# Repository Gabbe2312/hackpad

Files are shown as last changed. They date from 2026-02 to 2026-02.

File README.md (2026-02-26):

# Hackpad

Hackpad is a hardware-assisted penetration testing input device designed to accelerate reconnaissance workflows.  
It combines a physical keypad interface with USB HID keyboard emulation to launch predefined security tools directly from a target system.

⚠ This tool is intended strictly for authorized security testing and educational purposes.

---

## Photos

Hackpad Top

**More angles:**
Hackpad Side
Hackpad Desk
Hackpad Buttons

## How It Works

1. User enters target IPv4 address.
2. Optional TCP port can be specified.
3. One or more tools are selected.
4. Hackpad opens a terminal (Hyprland Super+Enter).
5. The selected commands are typed automatically via USB HID.

No software is installed on the target system — the device acts as a keyboard.

---

## Physical Key Layout

The keypad is physically labeled for intuitive operation (Mode, Clear, Port, Backspace, Enter, Opt1–Opt3, Hack).  
Internally, the firmware maps these labels to key events as follows:

| Button label | Firmware key | Function |
|---|---:|---|
| Mode | `M` | Switch between IP and Web tool banks |
| Clear | `C` | Clear current input (IP/port) |
| Port | `P` | Toggle between IP and Port edit mode |
| Backspace | `B` | Delete last character |
| Enter | `E` | Validate + save current input |
| Opt1 | `n` | Toggle tool 1 (Nmap / sqlmap) |
| Opt2 | `i` | Toggle tool 2 (Nikto / WhatWeb) |
| Opt3 | `g` | Toggle tool 3 (Gobuster / theHarvester) |
| Hack | `h` | Execute selected tools |

## Features

- IPv4 and TCP port input via physical keypad
- Dual tool banks (IP tools / Web tools)
- Integrated 16x2 I2C LCD interface
- USB HID keyboard emulation (no drivers required)
- Norwegian keyboard layout support
- Input validation (IPv4 + port range checking)
- Modular command execution per selected tool

---

## Supported Tools

### IP Tool Bank
- Nmap
- Nikto
- Gobuster

### Web Tool Bank
- sqlmap
- WhatWeb
- theHarvester

---

## Hardware Overview

- Arduino Pro Micro (ATmega32U4)
- 4x5 matrix keypad
- 16x2 I2C LCD display (0x27)
- USB connection to host machine

---

## Physical Interface

Hackpad Top

The keypad is physically labeled for intuitive operation:

| Button label | Firmware key | Function |
|---|---:|---|
| Mode | M | Switch between IP and Web tool banks |
| Clear | C | Clear current input (IP/port) |
| Port | P | Toggle between IP and Port edit mode |
| Backspace | B | Delete last character |
| Enter | E | Save current input |
| Opt1 | n | Toggle tool 1 (Nmap / sqlmap) |
| Opt2 | i | Toggle tool 2 (Nikto / WhatWeb) |
| Opt3 | g | Toggle tool 3 (Gobuster / theHarvester) |
| Hack | h | Execute selected tools |

## Building / Flashing

### Required Libraries
- Keypad
- LiquidCrystal_I2C
- HID-Project (NicoHood)

Board selection:
- Arduino Leonardo / Pro Micro (ATmega32U4)

Upload via Arduino IDE.

---

# Hardware 

## Microcontroller
- Arduino Pro Micro (ATmega32U4, 5V / 16MHz)

## Display
- 16x2 LCD Display
- I2C Backpack (PCF8574, address 0x27)

## Input System
- 20x Mechanical switches (4x5 matrix)
- 20x 1N4148 diodes
- Handwired matrix

## Enclosure
- 3D printed case (PLA)
- 3D printed keycaps with engraved labels

## Additional
- USB cable (Micro-USB)
- Jumper wires

## 3D Enclosure

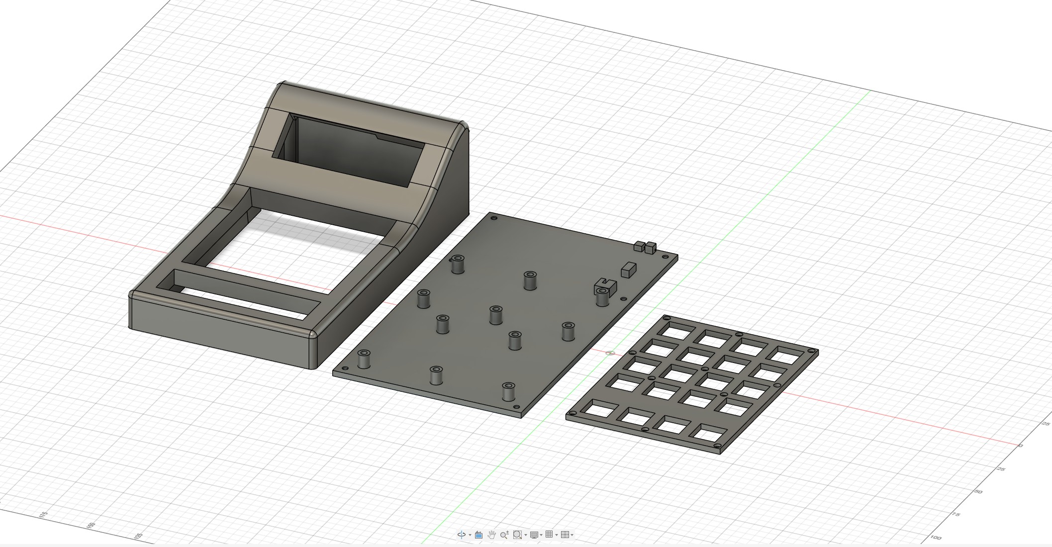
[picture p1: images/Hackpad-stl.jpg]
Hackpad Stl


The 3D printable enclosure files are available in:

hardware/enclosure/

The design includes:
- Main case
- Top plate
- Keycap set

## Roadmap

- OLED display support
- Command profile presets
- On-device logging
- Wireless version (ESP32)
- Modular plugin architecture

---

## Disclaimer

This project is provided for educational and authorized penetration testing use only.  
The author assumes no responsibility for misuse.

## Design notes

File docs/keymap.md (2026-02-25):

# Keymap Reference

## General Controls

| Key | Function |
|---|---|
| M | Switch between IP and Web tool banks |
| P | Toggle between IP and Port edit mode |
| E | Save current input |
| B | Backspace |
| C | Clear current input |
| h | Execute selected tools |

## Tool Selection Keys

| Key | IP Bank | Web Bank |
|---|---|---|
| n | Nmap | sqlmap |
| i | Nikto | WhatWeb |
| g | Gobuster | theHarvester |

## Input

- Numeric keys (0–9) → IP / Port input
- '.' → IPv4 separator

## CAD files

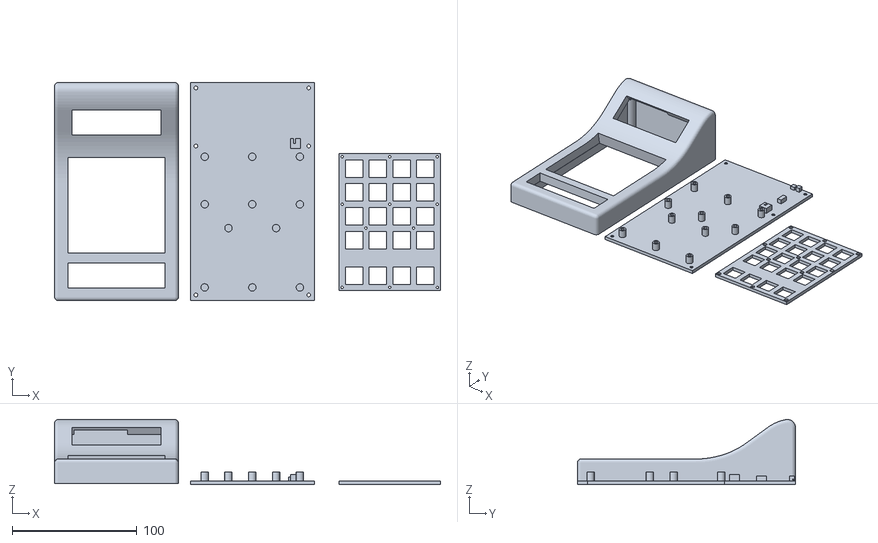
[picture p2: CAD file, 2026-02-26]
hardware/enclosure/Hackpad.stl
308.9 x 174.8 x 52.1

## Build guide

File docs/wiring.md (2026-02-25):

# Wiring Overview

## Microcontroller
Arduino Pro Micro (ATmega32U4)

## LCD (16x2 I2C)

- Address: 0x27
- VCC → 5V
- GND → GND
- SDA → SDA
- SCL → SCL

## Keypad Matrix

### Row Pins
- R1 → D8
- R2 → D9
- R3 → D10
- R4 → A2

### Column Pins
- C1 → D4
- C2 → D5
- C3 → D6
- C4 → D7
- C5 → A1

## USB

USB connection is used for:
- Power
- HID keyboard emulation

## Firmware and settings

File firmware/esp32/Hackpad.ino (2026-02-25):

#include <Keypad.h>
#include <Wire.h>
#include <LiquidCrystal_I2C.h>

// ------------------------------------------------------------
// Keyboard Layout Configuration
// ------------------------------------------------------------
// Must be defined BEFORE including HID-Project headers.
// Ensures correct key mapping for Norwegian keyboard layout.
#define LAYOUT_NORWEGIAN
#include <HID-Project.h>
#include <HID-Settings.h>

// ------------------------------------------------------------
// LCD Configuration (16x2 I2C Display)
// ------------------------------------------------------------
LiquidCrystal_I2C lcd(0x27, 16, 2);

// ------------------------------------------------------------
// Physical Keypad Wiring
// ------------------------------------------------------------
// Row and column pins correspond to physical keypad matrix.
byte rowPins[4] = {8, 9, 10, A2};
byte colPins[5] = {4, 5, 6, 7, A1};

// ------------------------------------------------------------
// Keymap Definition
// ------------------------------------------------------------
const byte ROWS = 4, COLS = 5;

char keys[ROWS][COLS] = {
  { '7','4','1','P','n' },
  { '8','5','2','0','i' },
  { '9','6','3','.', 'g' },
  { 'B','C','M','E','h' }
};

Keypad keypad = Keypad(makeKeymap(keys), rowPins, colPins, ROWS, COLS);

// ------------------------------------------------------------
// Operating Modes and State Management
// ------------------------------------------------------------
enum Bank { BANK_IP, BANK_WEB };
Bank bank = BANK_IP;

enum Edit { EDIT_IP, EDIT_PORT };
Edit editMode = EDIT_IP;

String ipDraft = "", ipSaved = "";
String portDraft = "";
uint16_t portSaved = 0;

// Tool selection flags
bool selNmap=false, selNikto=false, selGobuster=false;
bool selSqlmap=false, selWhatweb=false, selHarvester=false;

// ------------------------------------------------------------
// Input Validation Utilities
// ------------------------------------------------------------
static inline bool isDigitChar(char c){
  return c>='0' && c<='9';
}

// Validates IPv4 address format and value range
bool validIPv4(const String& ip){
  int n=ip.length();
  if(n<7||n>15) return false;

  int parts=0, i=0;

  while(i<n){
    if(ip[i]=='.') return false;

    int v=0, d=0;
    while(i<n && isDigitChar(ip[i])){
      v=v*10+(ip[i]-'0');
      if(++d>3) return false;
      i++;
    }

    if(d==0 || v>255) return false;

    parts++;
    if(parts==4) break;

    if(i>=n || ip[i]!='.') return false;
    i++;
  }

  return parts==4 && i==n;
}

// Validates TCP port range (1–65535)
bool validPort(const String& ps){
  if(ps.length()==0 || ps.length()>5) return false;

  for(char c: ps)
    if(!isDigitChar(c)) return false;

  long v = ps.toInt();
  return v>=1 && v<=65535;
}

// ------------------------------------------------------------
// LCD User Interface
// ------------------------------------------------------------
void draw(){
  lcd.clear();
  lcd.setCursor(0,0);

  if(editMode==EDIT_IP){
    lcd.print("IP:");
    lcd.print(ipDraft.length()? ipDraft :
              (ipSaved.length()? ipSaved : "-"));
  } else {
    lcd.print("PORT:");
    if(portDraft.length()) lcd.print(portDraft);
    else if(portSaved>0) lcd.print(portSaved);
    else lcd.print("-");
  }

  lcd.setCursor(0,1);

  if(bank==BANK_IP){
    if(selNmap) lcd.print("NM ");
    if(selNikto) lcd.print("NI ");
    if(selGobuster) lcd.print("GB ");
    if(!selNmap && !selNikto && !selGobuster)
      lcd.print("IP tools");
  } else {
    if(selSqlmap) lcd.print("SQ ");
    if(selWhatweb) lcd.print("WW ");
    if(selHarvester) lcd.print("TH ");
    if(!selSqlmap && !selWhatweb && !selHarvester)
      lcd.print("Web tools");
  }
}

// Temporary status message display
void flashMsg(const char* s, uint16_t ms=750){
  lcd.setCursor(0,1);
  lcd.print("                ");
  lcd.setCursor(0,1);
  lcd.print(s);
  delay(ms);
  draw();
}

// Toggle tool selection within current bank
void toggleTool(char k){
  if(bank==BANK_IP){
    if(k=='n') selNmap = !selNmap;
    if(k=='i') selNikto = !selNikto;
    if(k=='g') selGobuster = !selGobuster;
  } else {
    if(k=='n') selSqlmap = !selSqlmap;
    if(k=='i') selWhatweb = !selWhatweb;
    if(k=='g') selHarvester = !selHarvester;
  }
  draw();
}

// ------------------------------------------------------------
// Keyboard Output Helpers (Norwegian Layout)
// ------------------------------------------------------------

// Hyphen (-)
static inline void sendHyphen_NO(){
  BootKeyboard.press(KEY_SLASH);
  delay(2);
  BootKeyboard.release(KEY_SLASH);
  delay(2);
}

// Forward slash (/)
static inline void sendSlash_NO(){
  BootKeyboard.press(KEY_LEFT_SHIFT);
  BootKeyboard.press('7');
  delay(2);
  BootKeyboard.release('7');
  BootKeyboard.release(KEY_LEFT_SHIFT);
  delay(2);
}

// Colon (:)
static inline void sendColon_NO(){
  BootKeyboard.press(KEY_LEFT_SHIFT);
  BootKeyboard.press('.');
  delay(2);
  BootKeyboard.release('.');
  BootKeyboard.release(KEY_LEFT_SHIFT);
  delay(2);
}

// Generic key tap utility
static inline void tap(uint8_t key,
                       uint16_t down_ms=45,
                       uint16_t up_gap_ms=30) {
  BootKeyboard.press(key);
  delay(down_ms);
  BootKeyboard.release(key);
  delay(up_gap_ms);
}

// Opens terminal using Super + Enter (Hyprland)
void openTerminal(){
  BootKeyboard.press(KEY_LEFT_GUI);
  delay(40);
  BootKeyboard.write(KEY_ENTER);
  BootKeyboard.release(KEY_LEFT_GUI);
  delay(800);
}

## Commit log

2026-02-25 Add ESP32 firmware
2026-02-26 Fix image filename case mismatch
2026-02-26 Add enclosure STL files
    [Hackpad.stl]
2026-02-26 Added stl picture
